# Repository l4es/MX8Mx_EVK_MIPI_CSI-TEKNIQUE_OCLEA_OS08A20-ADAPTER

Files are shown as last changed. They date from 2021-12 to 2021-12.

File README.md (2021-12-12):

# MX8Mx_EVK_MIPI_CSI-TEKNIQUE_OCLEA_OS08A20-ADAPTER
Adapter for interfacing Teknique's Oclea OS08a20 to MX8M Mini/Plus EVK

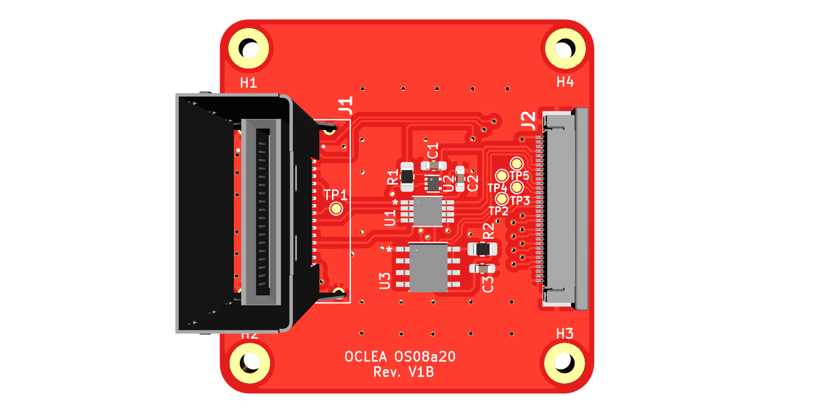
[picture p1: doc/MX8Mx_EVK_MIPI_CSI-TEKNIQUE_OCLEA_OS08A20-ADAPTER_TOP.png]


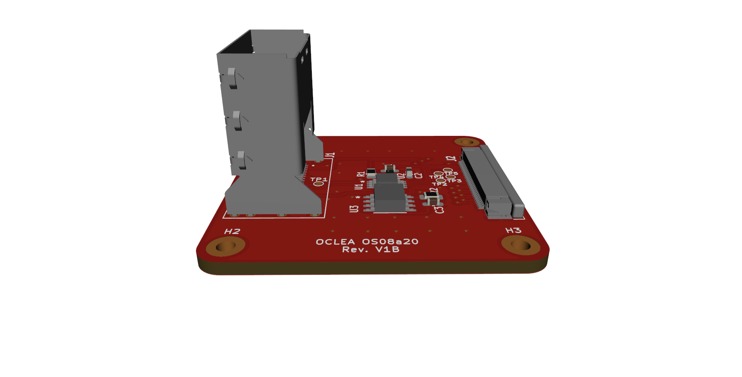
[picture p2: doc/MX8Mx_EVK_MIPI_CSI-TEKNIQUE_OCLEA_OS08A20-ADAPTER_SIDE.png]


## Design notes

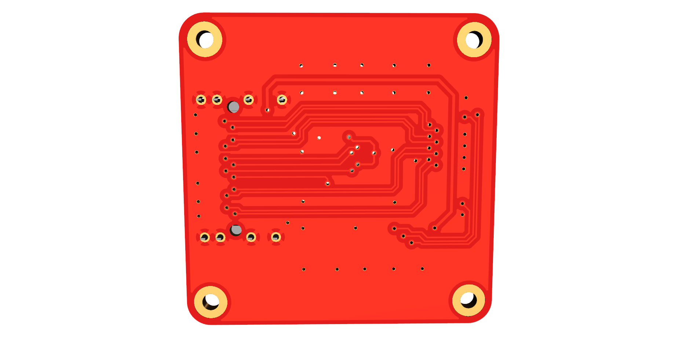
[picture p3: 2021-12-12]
doc/MX8Mx_EVK_MIPI_CSI-TEKNIQUE_OCLEA_OS08A20-ADAPTER_BOT.png

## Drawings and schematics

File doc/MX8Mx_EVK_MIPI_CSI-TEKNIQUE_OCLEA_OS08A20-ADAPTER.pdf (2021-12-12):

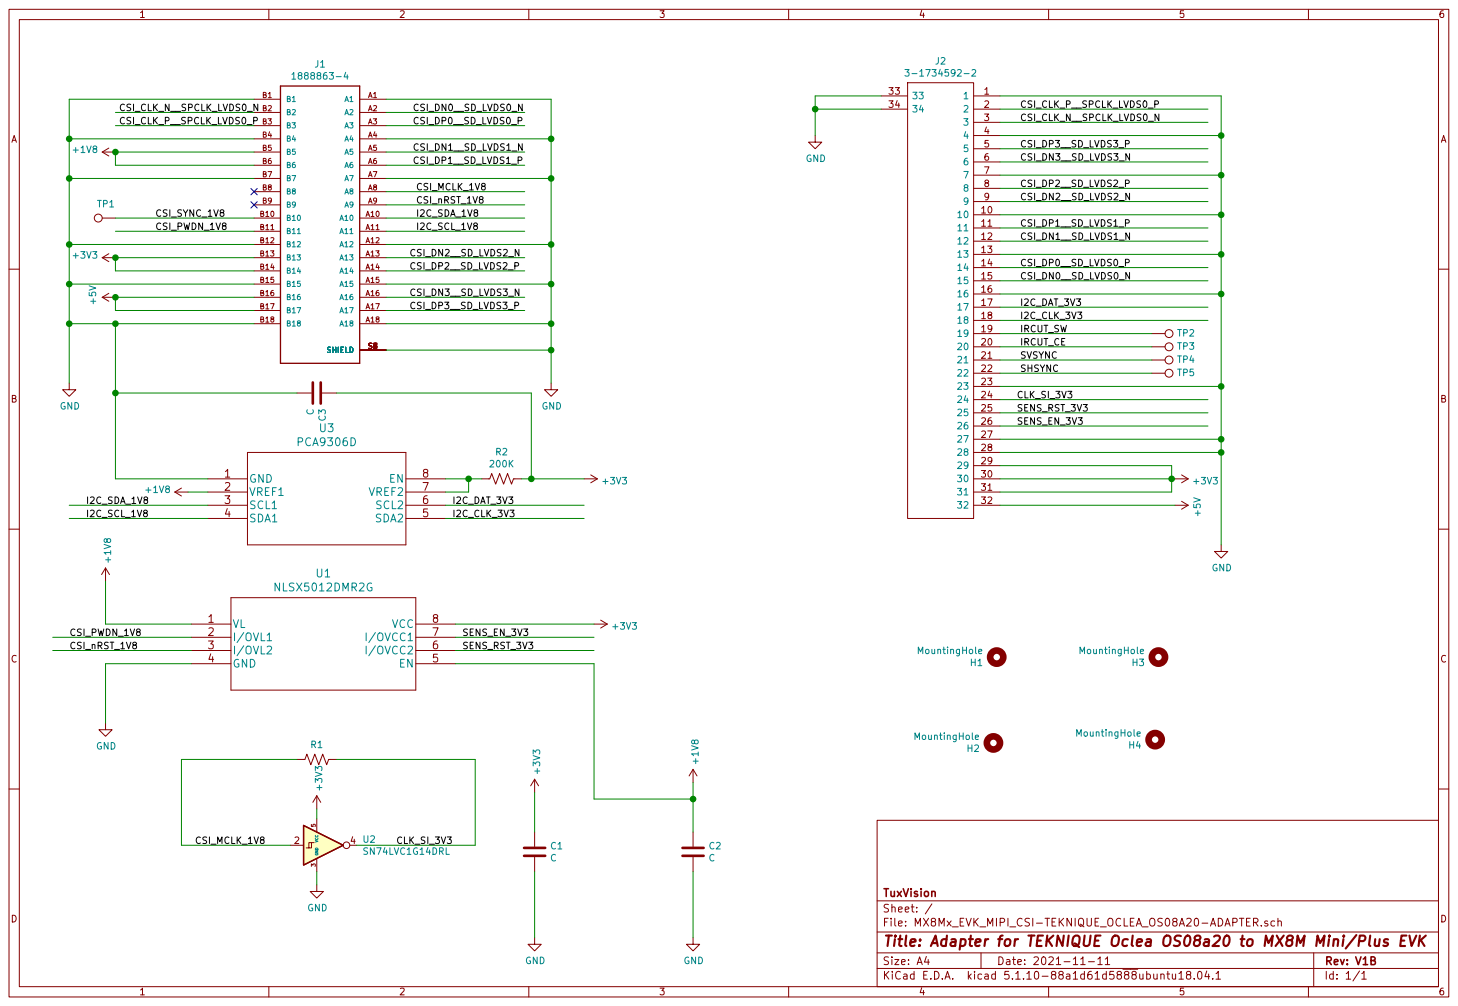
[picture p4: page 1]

File: MX8Mx_EVK_MIPI_CSI-TEKNIQUE_OCLEA_OS08A20-ADAPTER.sch Sheet: / TuxVision

Id: 1/1 Title: Adapter for TEKNIQUE Oclea OS08a20 to MX8M Mini/Plus EVK

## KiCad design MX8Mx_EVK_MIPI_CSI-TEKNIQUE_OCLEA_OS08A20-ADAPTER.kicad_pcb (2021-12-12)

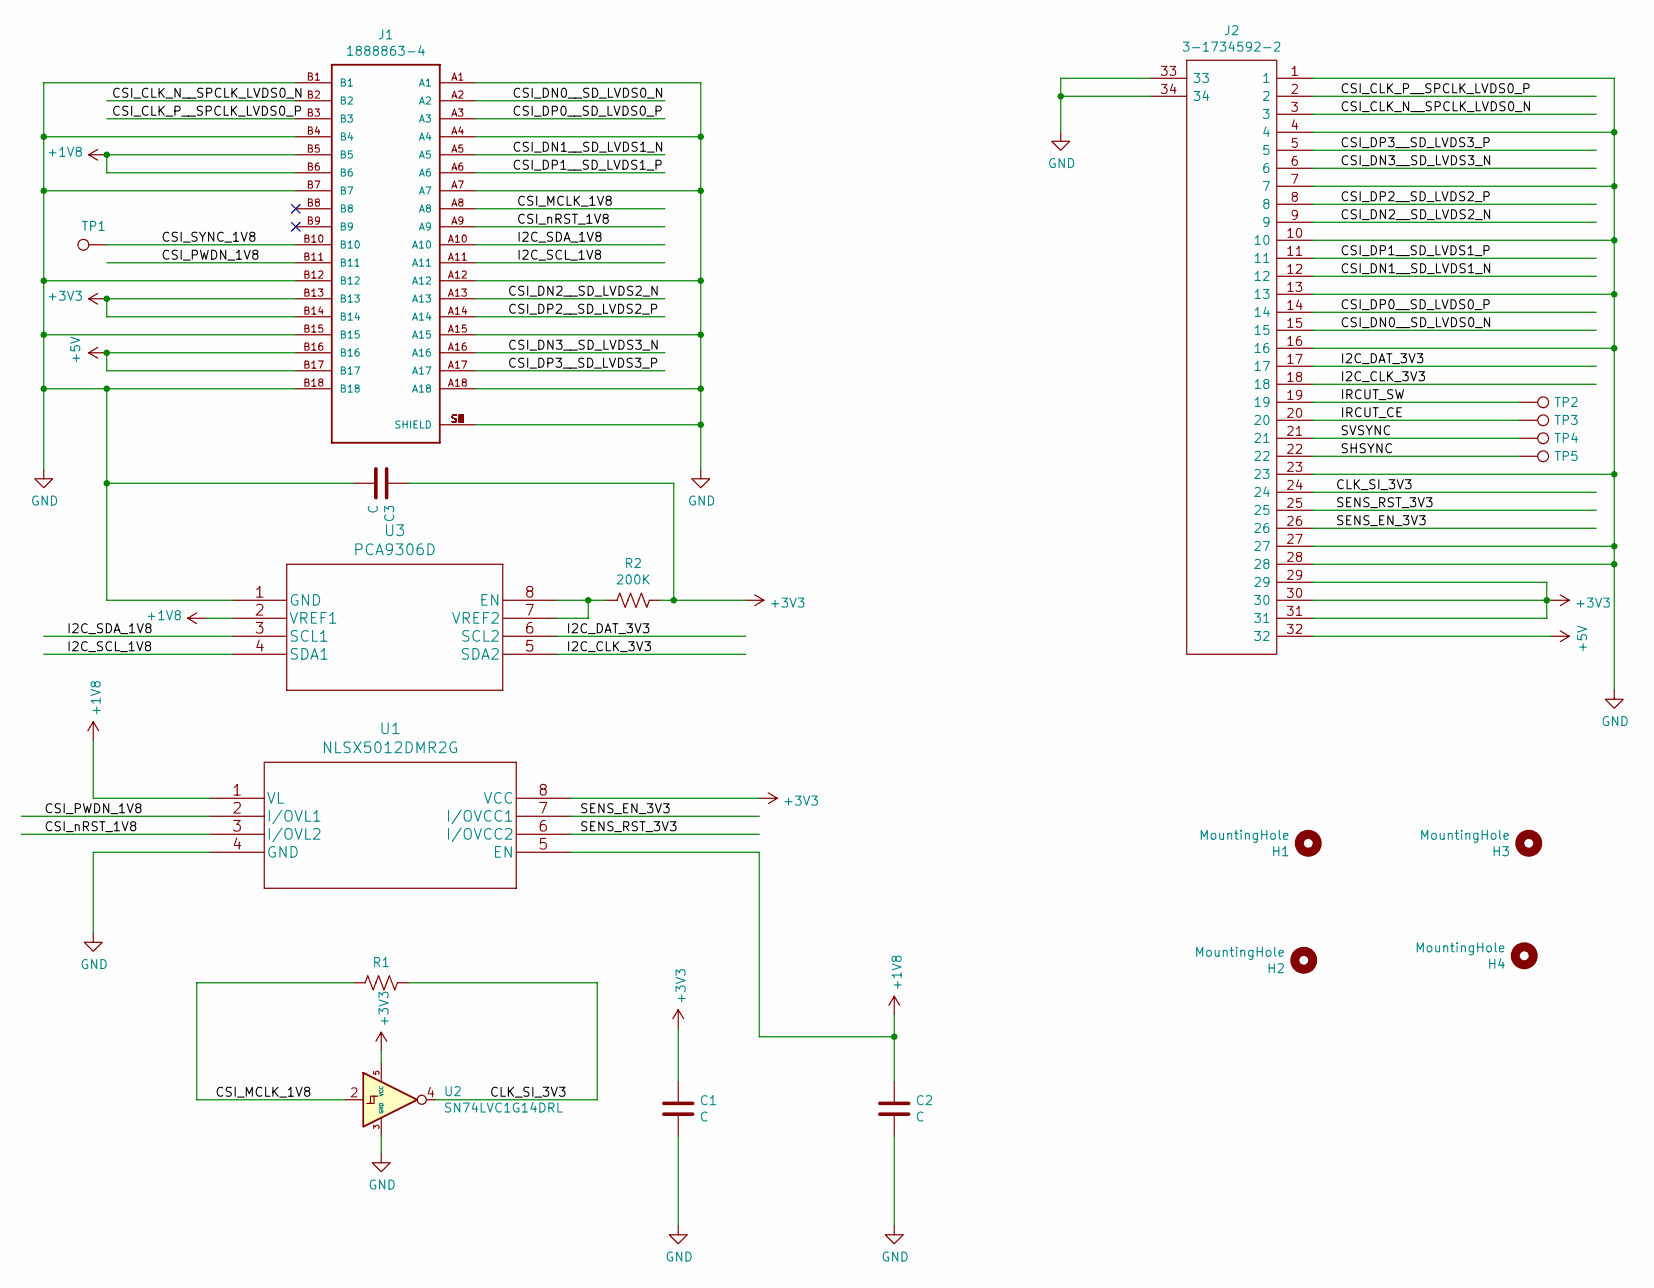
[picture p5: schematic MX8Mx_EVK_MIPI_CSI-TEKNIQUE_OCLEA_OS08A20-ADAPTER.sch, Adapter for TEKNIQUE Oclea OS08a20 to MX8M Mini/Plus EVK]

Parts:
C1, C2, C3: C; C_0603_1608Metric_Pad1.08x0.95mm_HandSolder
H1, H2, H3, H4: MountingHole; MountingHole_2.2mm_M2_Pad
J1: 1888863-4; TE_1888863-4
J2: 3-1734592-2; 317345922; Manufacturer_Part_Number 3-1734592-2; Mouser Part Number 571-3-1734592-2
R1: R_US; R_0805_2012Metric_Pad1.20x1.40mm_HandSolder
R2: 200K; R_0805_2012Metric_Pad1.20x1.40mm_HandSolder
TP1, TP2, TP3, TP4, TP5: TestPoint; TestPoint_Pad_D1.0mm
U1: NLSX5012DMR2G
U2: SN74LVC1G14DRL; SOT-553
U3: PCA9306D

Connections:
+1V8: C2.1, J1.B5, J1.B6, U1.1 (VL), U1.5 (EN), U3.2 (VREF1)
+3V3: C1.1, C3.1, J1.B13, J1.B14, J2.29, J2.30, J2.31, R2.1, U1.8 (VCC), U2.5 (VCC)
+5V: J1.B16, J1.B17, J2.32
/CLK_SI_3V3: J2.24, R1.1, U2.4
/CSI_CLK_N__SPCLK_LVDS0_N: J1.B2, J2.3
/CSI_CLK_P__SPCLK_LVDS0_P: J1.B3, J2.2
/CSI_DN0__SD_LVDS0_N: J1.A2, J2.15
/CSI_DN1__SD_LVDS1_N: J1.A5, J2.12
/CSI_DN2__SD_LVDS2_N: J1.A13, J2.9
/CSI_DN3__SD_LVDS3_N: J1.A16, J2.6
/CSI_DP0__SD_LVDS0_P: J1.A3, J2.14
/CSI_DP1__SD_LVDS1_P: J1.A6, J2.11
/CSI_DP2__SD_LVDS2_P: J1.A14, J2.8
/CSI_DP3__SD_LVDS3_P: J1.A17, J2.5
/CSI_MCLK_1V8: J1.A8, R1.2, U2.2
/CSI_PWDN_1V8: J1.B11, U1.2 (I/OVL1)
/CSI_SYNC_1V8: J1.B10, TP1.1
/CSI_nRST_1V8: J1.A9, U1.3 (I/OVL2)
/I2C_CLK_3V3: J2.18, U3.5 (SDA2)
/I2C_DAT_3V3: J2.17, U3.6 (SCL2)
/I2C_SCL_1V8: J1.A11, U3.4 (SDA1)
/I2C_SDA_1V8: J1.A10, U3.3 (SCL1)
/IRCUT_CE: J2.20, TP3.1
/IRCUT_SW: J2.19, TP2.1
/SENS_EN_3V3: J2.26, U1.7 (I/OVCC1)
/SENS_RST_3V3: J2.25, U1.6 (I/OVCC2)
/SHSYNC: J2.22, TP5.1
/SVSYNC: J2.21, TP4.1
GND: C1.2, C2.2, C3.2, J1.A1, J1.A4, J1.A7, J1.A12, J1.A15, J1.A18, J1.B1, J1.B4, J1.B7, J1.B12, J1.B15, J1.B18, J1.S1 (SHIELD), J1.S2 (SHIELD), J1.S3 (SHIELD), J1.S4 (SHIELD), J1.S5 (SHIELD), J1.S6 (SHIELD), J1.S7 (SHIELD), J1.S8 (SHIELD), J2.1, J2.4, J2.7, J2.10, J2.13, J2.16, J2.23, J2.27, J2.28, J2.33, J2.34, U1.4 (GND), U2.3 (GND), U3.1 (GND)
unnamed: R2.2, U3.7 (VREF2), U3.8 (EN)

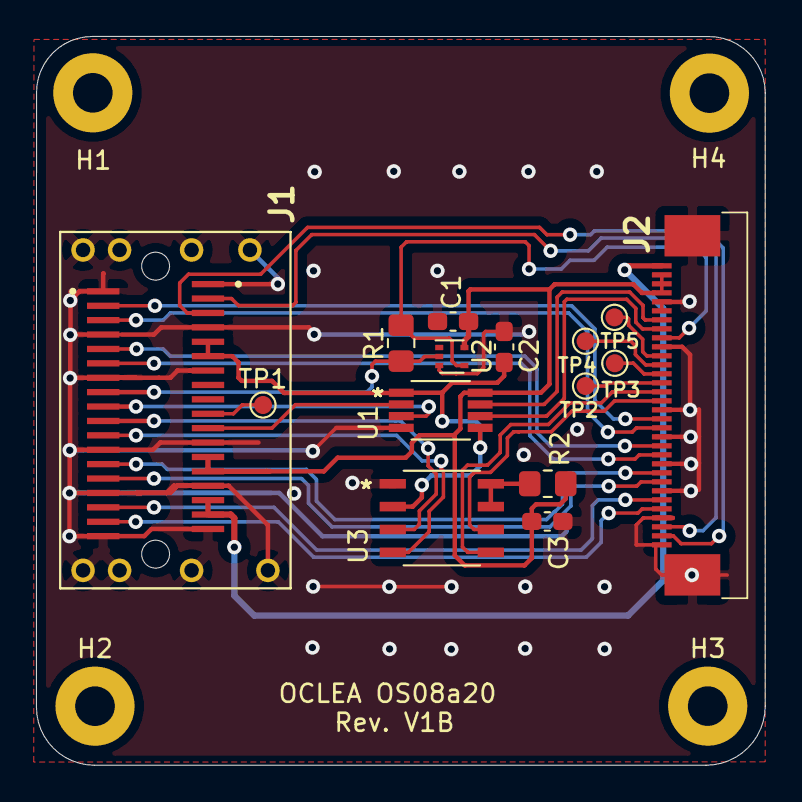
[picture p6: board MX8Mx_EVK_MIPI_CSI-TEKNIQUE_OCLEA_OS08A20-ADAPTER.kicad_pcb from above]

Board: 2 copper layers, 40.5 x 40.5 mm, 19 parts (0 on the bottom side), 30 nets.

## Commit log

2021-08-06 Completed layout (J1 might need to be Y mirrored)
    [MX8Mx_EVK_MIPI_CSI-TEKNIQUE_OCLEA_OS08A20-ADAPTER.kicad_pcb, MX8Mx_EVK_MIPI_CSI-TEKNIQUE_OCLEA_OS08A20-ADAPTER.sch]
2021-08-07 Mirror J1 signals (A-side to B-side and vice-versa) for mating with the MIPI-CSI interface(s) on EVK
    [MX8Mx_EVK_MIPI_CSI-TEKNIQUE_OCLEA_OS08A20-ADAPTER.kicad_pcb, MX8Mx_EVK_MIPI_CSI-TEKNIQUE_OCLEA_OS08A20-ADAPTER.sch]
2021-08-07 Change 32-pin connector from Omron XF2M-3215-1A to TE 3-1734592-2
    [MX8Mx_EVK_MIPI_CSI-TEKNIQUE_OCLEA_OS08A20-ADAPTER.kicad_pcb, MX8Mx_EVK_MIPI_CSI-TEKNIQUE_OCLEA_OS08A20-ADAPTER.sch]
2021-08-07 Add round-corners
    [MX8Mx_EVK_MIPI_CSI-TEKNIQUE_OCLEA_OS08A20-ADAPTER.kicad_pcb]
2021-08-07 Add first production release V1A
    [MX8Mx_EVK_MIPI_CSI-TEKNIQUE_OCLEA_OS08A20-ADAPTER-B_Cu.gbr, MX8Mx_EVK_MIPI_CSI-TEKNIQUE_OCLEA_OS08A20-ADAPTER-B_Mask.gbr, MX8Mx_EVK_MIPI_CSI-TEKNIQUE_OCLEA_OS0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]
2021-11-10 MX8Mx_EVK_MIPI_CSI-TEKNIQUE_OCLEA_OS08A20-ADAPTER.sch : Edit title block (title, date, revision)
    [MX8Mx_EVK_MIPI_CSI-TEKNIQUE_OCLEA_OS08A20-ADAPTER.sch]
2021-11-10 Update V1A revision
    [MX8Mx_EVK_MIPI_CSI-TEKNIQUE_OCLEA_OS08A20-ADAPTER-B_Cu.gbr, MX8Mx_EVK_MIPI_CSI-TEKNIQUE_OCLEA_OS08A20-ADAPTER-B_Mask.gbr, MX8Mx_EVK_MIPI_CSI-TEKNIQUE_OCLEA_OS0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]
2021-11-11 Update design with separate I2C and GPIO level translators
    [MX8Mx_EVK_MIPI_CSI-TEKNIQUE_OCLEA_OS08A20-ADAPTER.sch]
2021-11-11 Complete routing of new design with separate I2C and GPIO level translators
    [MX8Mx_EVK_MIPI_CSI-TEKNIQUE_OCLEA_OS08A20-ADAPTER.kicad_pcb]
2021-12-12 Add production data for release V1B
    [MX8Mx_EVK_MIPI_CSI-TEKNIQUE_OCLEA_OS08A20-ADAPTER-B_Cu.gbr, MX8Mx_EVK_MIPI_CSI-TEKNIQUE_OCLEA_OS08A20-ADAPTER-B_Mask.gbr, MX8Mx_EVK_MIPI_CSI-TEKNIQUE_OCLEA_OS0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]

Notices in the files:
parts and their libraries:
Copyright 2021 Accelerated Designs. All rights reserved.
